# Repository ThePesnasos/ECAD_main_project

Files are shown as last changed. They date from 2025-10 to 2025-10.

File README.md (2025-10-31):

# ECAD_main_project
# Печатная плата для аналогового и цифровго трактов ЭЭГ
Для сборки аппарата ЭЭГ необходимо произвести 8 плат аналоговго тракта и 1 плату цифрового.
Плата цифрового тракта объединяется с 8 платами аналогового тракта

# TODO
1. В результате разводки платы выявлено отсутвие пинов для подключения питания 5В и 3,3 В.
Необходимо доработать схемотехническую часть, использовать разъёмы с большим числом пинов.

2. Предусмотреть отверстия под крепления печатных плат в корпусе устройства.

3. Рассмотреть возможность создания третьей "материнской", чтобы избежать использования разъемов с проводами внутри прибора.

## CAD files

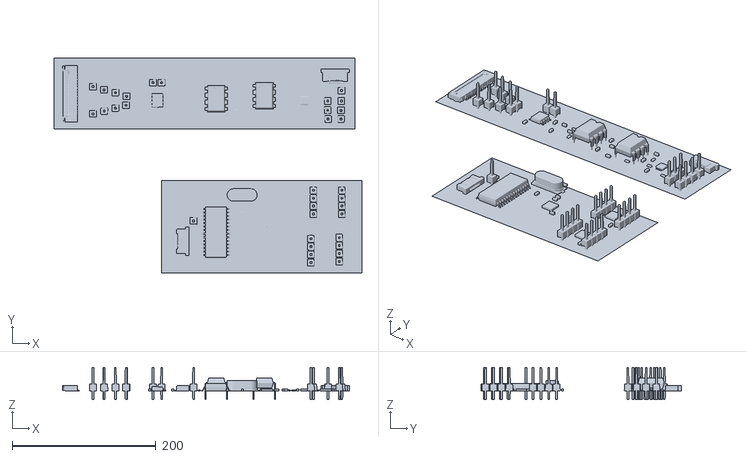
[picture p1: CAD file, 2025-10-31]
Resultati/3D/OBJ_PCB_Tashe.obj
428.8 x 298.8 x 45.2

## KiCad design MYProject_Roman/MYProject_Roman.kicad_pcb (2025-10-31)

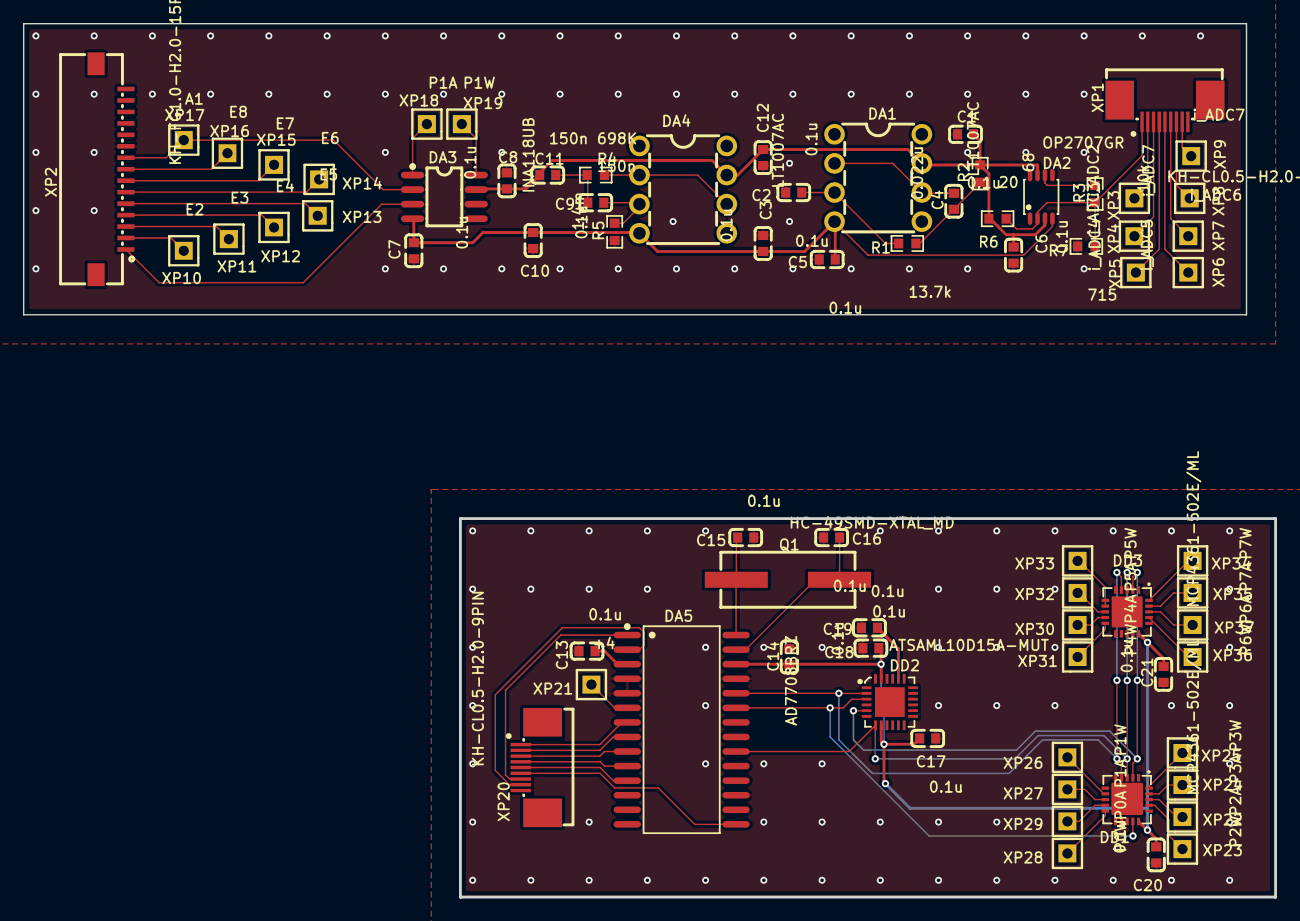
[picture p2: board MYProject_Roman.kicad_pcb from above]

Board: 2 copper layers, 109.2 x 76.2 mm, 75 parts (0 on the bottom side), 62 nets.

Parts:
C1, C2, C3, C5, C6, C7, C8, C10, C12, C13, C14, C15, C16, C17, C18, C19, C20, C21: 0.1u; C0603
C4: 0.022u; C0603
C9, C11: 150n; C0603
DA1, DA4: LT1007AC; PDIP-8_L9.3-W6.4-P2.54-LS7.6-BL
DA2: OP2707GR; MSOP-8_L2.9-W2.8-P0.65-LS4.0-BL
DA3: INA118UB; SOIC-8_L4.9-W3.9-P1.27-LS6.2-BL
DA5: AD7708BRZ; SOIC-28_L17.9-W7.5-P1.27-LS10.3-BL
DD1, DD3: MCP4361-502E/ML; QFN-20_L4.0-W4.0-P0.50-TL-EP2.7
DD2: ATSAML10D15A-MUT; WQFN-24_L4.0-W4.0-P0.50-TL-EP2.6
Pad_gge10147: Pad_gge10147
Q1: HC-49SMD-XTAL_MD; CRYSTAL-SMD_L11.4-W4.8-LS12.7
R1: 13.7k; R0603
R2: 68; R0603
R3: 10k; R0603
R4: 698K; R0603
R5: 1.4m; R0603
R6: 20; R0603
R7: 715; R0603
XP1, XP20: KH-CL0.5-H2.0-9PIN; FPC-SMD_9P-P0.50_KINGHELM_KH-CL0.5-H2.0-9PIN
XP2: KH-FG1.0-H2.0-15PIN; FPC-SMD_15P-P1.0_KINGHELM_KH-FG1.0-H2.0-15PIN
XP3: i_ADC2; HDR-M-2.54_1X1
XP4: i_ADC3; HDR-M-2.54_1X1
XP5: i_ADC4; HDR-M-2.54_1X1
XP6: i_ADC5; HDR-M-2.54_1X1
XP7: i_ADC6; HDR-M-2.54_1X1
XP8, XP9: i_ADC7; HDR-M-2.54_1X1
XP10: E2; HDR-M-2.54_1X1
XP11: E3; HDR-M-2.54_1X1
XP12: E4; HDR-M-2.54_1X1
XP13: E5; HDR-M-2.54_1X1
XP14: E6; HDR-M-2.54_1X1
XP15: E7; HDR-M-2.54_1X1
XP16: E8; HDR-M-2.54_1X1
XP17: A1; HDR-M-2.54_1X1
XP18, XP27: P1A; HDR-M-2.54_1X1
XP19, XP26: P1W; HDR-M-2.54_1X1
XP21: +4; HDR-M-2.54_1X1
XP22: P2A; HDR-M-2.54_1X1
XP23: P2W; HDR-M-2.54_1X1
XP24: P3A; HDR-M-2.54_1X1
XP25: P3W; HDR-M-2.54_1X1
XP28: P0W; HDR-M-2.54_1X1
XP29: P0A; HDR-M-2.54_1X1
XP30: P4A; HDR-M-2.54_1X1
XP31: P4W; HDR-M-2.54_1X1
XP32: P5A; HDR-M-2.54_1X1
XP33: P5W; HDR-M-2.54_1X1
XP34: P7W; HDR-M-2.54_1X1
XP35: P7A; HDR-M-2.54_1X1
XP36: P6W; HDR-M-2.54_1X1
XP37: P6A; HDR-M-2.54_1X1

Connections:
+3,3V: C14.2, C17.2, C18.2, C20.2, C21.2, DA5.26, DD1.15, DD2.8, DD2.23, DD3.15
+5V: C1.1, C6.1, C8.1, C11.1, C12.1, C13.2, DA1.7, DA2.3, DA2.7, DA3.7, DA4.7, DA5.3, R2.1, R6.1
-5V: C3.1, C5.1, C7.1, C10.1, DA1.4, DA2.4, DA3.4, DA4.4
DA1_2: C4.2, DA1.2, DA1.6
DA1_3: C2.1, DA1.3, R1.2
DA2_2: DA2.2, R3.2, R6.2, R7.1, XP1.1
DA2_6: DA2.6, R3.1
DA3_1: DA3.1, XP18.1
DA3_8: DA3.8, XP19.1
DA4_2: DA4.2, DA4.6, R4.2
DA4_3: C9.2, DA4.3, R5.2
DA5_6: DA5.6, XP21.1
DA5_20: DA5.20, DD1.3, DD2.7, DD3.3
DA5_23: DA5.23, DD1.14, DD2.3
DA5_24: DA5.24, DD1.4, DD2.2, DD3.4
DA5_27: C16.1, DA5.27, Q1.2
DA5_28: C15.1, DA5.28, Q1.1
DD1_7: DD1.7, XP26.1
DD1_8: DD1.8, XP27.1
DD1_9: DD1.9, XP29.1
DD1_10: DD1.10, XP28.1
DD1_17: DD1.17, XP23.1
DD1_18: DD1.18, XP22.1
DD1_19: DD1.19, XP24.1
DD1_20: DD1.20, XP25.1
DD2_5: DD1.2, DD2.5, DD3.2
DD2_20: C19.2, DD2.20
DD3_7: DD3.7, XP33.1
DD3_8: DD3.8, XP32.1
DD3_9: DD3.9, XP30.1
DD3_10: DD3.10, XP31.1
DD3_17: DD3.17, XP36.1
DD3_18: DD3.18, XP37.1
DD3_19: DD3.19, XP35.1
DD3_20: DD3.20, XP34.1
GND: C1.2, C2.2, C3.2, C5.2, C6.2, C7.2, C8.2, C10.2, C12.2, C13.1, C14.1, C15.2, C16.2, C17.1, C18.1, C19.1, C20.1, C21.1, DA5.4, DA5.5, DA5.17, DA5.25, DD1.5, DD2.9, DD3.5, R5.1, R7.2, XP2.10
R1_1: C4.1, R1.1, R2.2
R4_1: C9.1, C11.2, R4.1
XP1_2: XP1.2, XP3.1
XP1_3: XP1.3, XP4.1
XP1_4: XP1.4, XP5.1
XP1_5: XP1.5, XP6.1
XP1_6: XP1.6, XP7.1
XP1_7: XP1.7, XP8.1
XP1_8: XP1.8, XP9.1
XP2_1: DA3.3, XP2.1
XP2_2: XP2.2, XP10.1
XP2_3: XP2.3, XP11.1
XP2_4: XP2.4, XP12.1
XP2_5: XP2.5, XP13.1
XP2_6: XP2.6, XP14.1
XP2_7: XP2.7, XP15.1
XP2_8: XP2.8, XP16.1
XP2_9: DA3.2, XP2.9, XP17.1
XP20_1: DA5.7, XP20.1
XP20_2: DA5.8, XP20.2
XP20_3: DA5.9, XP20.3
XP20_4: DA5.10, XP20.4
XP20_5: DA5.11, XP20.5
XP20_6: DA5.15, XP20.6
XP20_7: DA5.1, XP20.7
XP20_8: DA5.2, XP20.8

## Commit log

2025-10-31 Добавлена папка с результатами работы. Добавлена электрическая схема обоих плат
    [principal.kicad_sch]
2025-10-31 Добавлена разводка
    [plates.kicad_pcb]
2025-10-31 Добавлены гербер файлы и файлы сверления
    [Drill_PTH_Through.DRL, Drill_PTH_Through_Via.DRL, Gerber_BoardOutlineLayer.GKO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]
2025-10-31 Добавлены 3D модели
    [OBJ_PCB_Tashe.obj]
2025-10-31 Добавлена копия проекта
    [MYProject_Roman.kicad_pcb, MYProject_Roman.kicad_sch]
2025-10-31 Обновлён README файл
